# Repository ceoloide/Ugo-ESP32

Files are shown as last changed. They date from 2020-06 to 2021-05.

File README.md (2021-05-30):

# Ugo-ESP32

A 4-button Wi-Fi connected remote, based on the original [Hugo-ESP8266 concept by mcer12](https://github.com/mcer12/Hugo-ESP8266).

## Features

-   4 physical buttons that can trigger up to 7 different actions, one for each button and three for 2-button combinations (B1+B2, B2+B3, B3+B4).
-   Support for Home Assistant auto-discovery, optionally sending device state (button, battery percentage, voltage) after every button push.
-   Support for HTTPS and MQTTS endpoints, although certificate validation is planned but not yet supported.
-   Web UI to configure WiFi and button actions.

## TinyPICO

The code currently depends on a [TinyPICO (original)](https://tinypico.com), since I'm using this board for development. TinyPICO has been selected for its very good low-power draw on deep sleep. Check out Unexpected Maker's [Discord server](https://discord.gg/83Nr7rz) for updates and questions on TinyPICO or this project.

### Ugo-ESP32 TinyPICO Shield

The hardware folder contains the PCB and schematics for a TinyPICO shield version of the Ugo-ESP32, featuring similar overall dimensions (35mm width, 145mm height) and button layout as the [Philips Hue Dimmer Switch](https://www2.meethue.com/en-us/p/hue-dimmer-switch/046677473372), as well as an RGB led for status notifications. It also contains the enclosure design and STL files, which are meant for 3D printing.

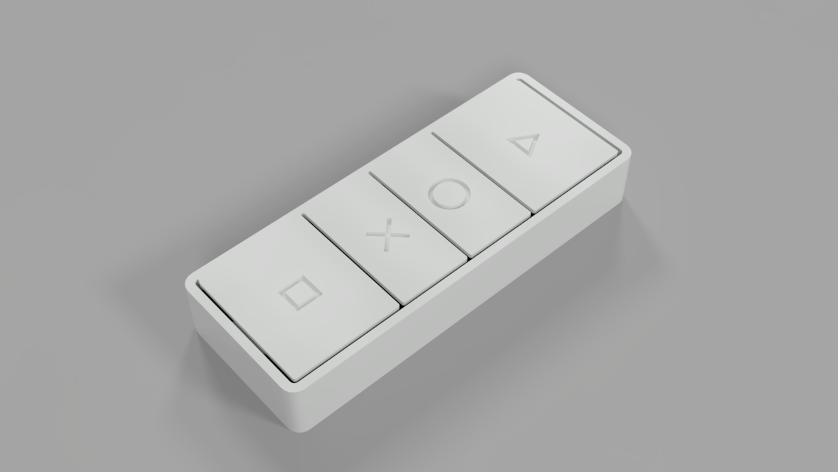
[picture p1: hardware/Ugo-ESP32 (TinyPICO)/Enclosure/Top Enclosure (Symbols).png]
Enclosure top


The board houses the TinyPICO on the back, and can comfortably fit a 60x30x5mm (503060 / 053060) LiPo battery, usually available with a 1300mAh capacity. Early and untested estimates indicate a battery life of roughly 1 year with up to 2 button presses per day.

PCB front

PCB back

## Credits

A huge thanks to:
- [@mcer12](https://github.com/mcer12) for the original [Hugo-ESP8266 concept](https://github.com/mcer12/Hugo-ESP8266)

Shoutout to everyone working on the libraries used for this project:
- [ArduinoJson](https://github.com/bblanchon/ArduinoJson)
- [AsyncTCP](https://github.com/me-no-dev/AsyncTCP)
- [ESPAsyncWebServer](https://github.com/me-no-dev/ESPAsyncWebServer)
- [PubSubClient](https://github.com/knolleary/pubsubclient)
- [TinyPICO-Helper](https://github.com/)

## License 

This software is licensed under the APACHE 2.0 License. See the [license file](LICENSE) for details.

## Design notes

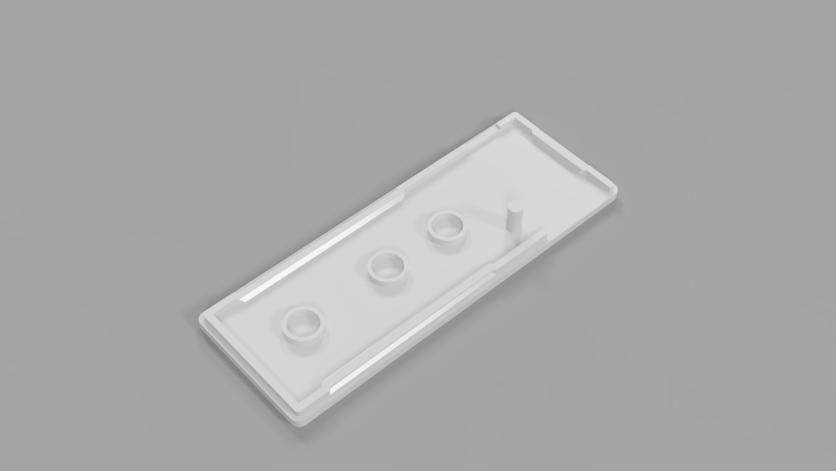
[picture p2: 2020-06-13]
hardware/Ugo-ESP32 (TinyPICO)/Enclosure/Bottom Lid.png

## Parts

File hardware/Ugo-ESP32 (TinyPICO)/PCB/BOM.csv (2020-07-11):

ID | Name | Designator | Footprint | Quantity | Manufacturer Part | Manufacturer | Supplier | Supplier Part | LCSC Assembly
1 | 10uF | C1,C2,C3,C4 | C0603 | 4 | CL10A106KP8NNNC | SAMSUNG | LCSC | C19702 | Yes
2 | 100K | R1,R2,R3,R4 | R0603 | 4 | 0603WAF1003T5E | UniOhm | LCSC | C25803 | Yes
3 | TS-1187A-C-C-B | SW1,SW2,SW3,SW4 | SW-SMD_4P-L5.1-W5.1-P3.70-LS6.4 | 4 | TS-1187A-C-C-B | XKB Enterprise | LCSC | C318889 | Yes
4 | MHT194CRGBCT | D5 | LED-ARRAY-SMD_0603-4P-L1.6-W1.6-BL-RD | 1 | MHT194CRGBCT | MEIHUA | LCSC | C404275 | Yes
5 | M02-JST-2MM-SMT | JP1 | JST-2-SMD | 1
6 | 270 | R5 | R0603 | 1 | 0603WAF2700T5E | UniOhm | LCSC | C22966 | Yes
7 | 820 | R6 | R0603 | 1 | 0603WAF8200T5E | UniOhm | LCSC | C23253 | Yes
8 | 10 | R8 | R0402 | 1 | 0402WGF100JTCE | UniOhm | LCSC | C25077 | Yes
9 | 47 | R7 | R0603 | 1 | 0603WAF470JT5E | UniOhm | LCSC | C23182 | Yes
10 | TinyPICO | NO | TINYPICO | 1 | TinyPICO | Unexpected Maker | Unexpected Maker | TinyPICO

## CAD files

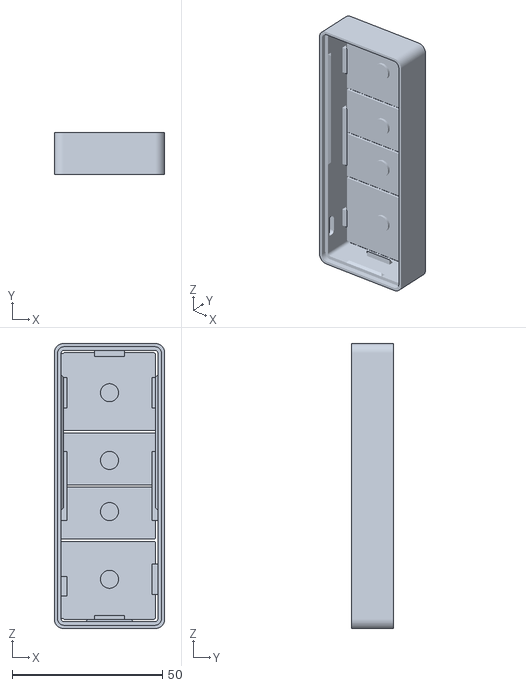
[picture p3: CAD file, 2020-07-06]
hardware/Ugo-ESP32 (TinyPICO)/Enclosure/Top Enclosure (Symbols).stl
36.7 x 14.0 x 94.7

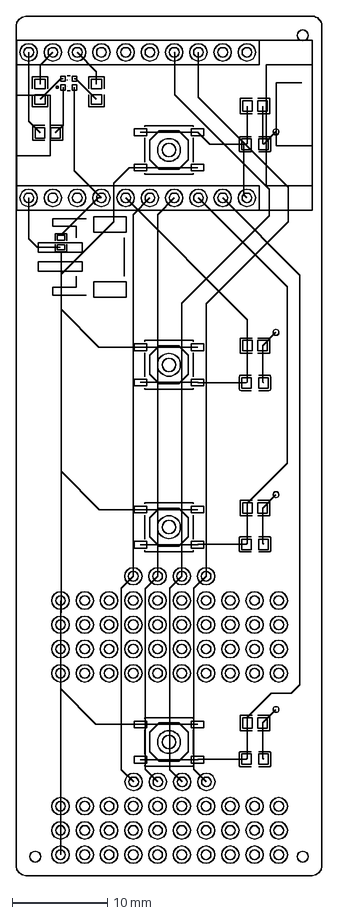
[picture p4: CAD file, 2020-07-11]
hardware/Ugo-ESP32 (TinyPICO)/PCB/EasyEDA/EasyEDA_PCB.dxf
32.0 x 90.0 mm

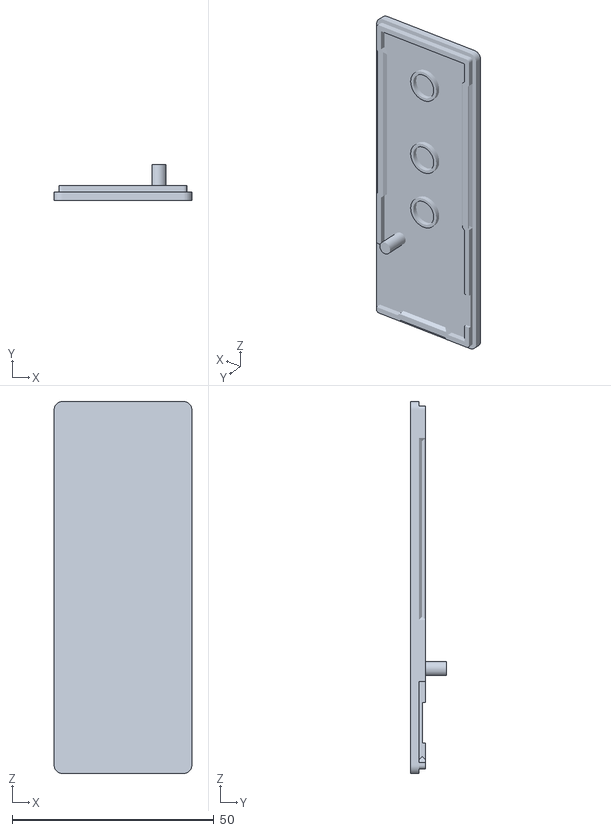
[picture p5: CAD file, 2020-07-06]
hardware/Ugo-ESP32 (TinyPICO)/Enclosure/Bottom Lid.stl
34.1 x 8.80 x 92.1

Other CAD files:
hardware/Ugo-ESP32 (TinyPICO)/Enclosure/Top Enclosure (Plain).stl
hardware/Ugo-ESP32 (TinyPICO)/Enclosure/Ugo-ESP32 (TinyPICO).f3d

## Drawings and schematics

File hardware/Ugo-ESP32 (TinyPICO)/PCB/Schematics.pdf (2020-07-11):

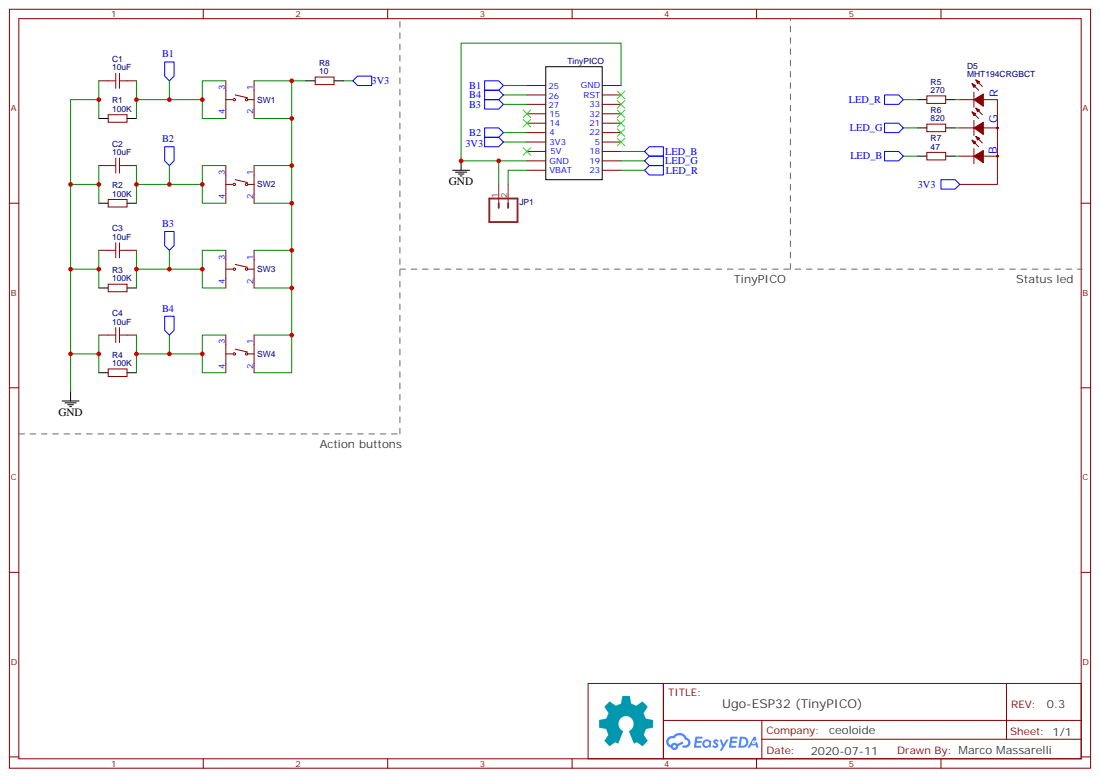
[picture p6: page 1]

Drawn By: Marco Massarelli

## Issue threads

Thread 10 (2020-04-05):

When serving reset.html the CSS is not delivered before device reset

ceoloide, 2020-04-05:
The CSS of the reset.html page is not delivered in time for display before the device goes into sleep and resets. This is related to Issue #4.

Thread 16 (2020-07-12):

Fix minor imperfections in the enclosure

ceoloide, 2020-07-12:
- Length should be increased from 90.2mm to ~90.45mm
- Material should be added again on the back of the buttons to avoid symbols looking bad
- Revert the change in slit size between buttons since it looks worse in practice

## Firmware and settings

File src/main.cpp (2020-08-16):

/*
Copyright 2020 Marco Massarelli

Licensed under the Apache License, Version 2.0 (the "License");
you may not use this file except in compliance with the License.
You may obtain a copy of the License at

    http://www.apache.org/licenses/LICENSE-2.0

Unless required by applicable law or agreed to in writing, software
distributed under the License is distributed on an "AS IS" BASIS,
WITHOUT WARRANTIES OR CONDITIONS OF ANY KIND, either express or implied.
See the License for the specific language governing permissions and
limitations under the License.
*/

#include <Arduino.h>
#include <TinyPICO.h>
#include "main.h"

// Initialise the TinyPICO library
TinyPICO tp = TinyPICO();

uint8_t deviceMode = NORMAL_MODE;

uint8_t button;

bool otaModeStarted = false;
volatile bool ledState = false;

// TIMERS
unsigned long otaMillis, ledMillis, configTimer, otaTimer;

byte mac[6];
AsyncWebServer server(80);

byte dnsPort = 53;
DNSServer dnsServer;

WiFiClient espClientInsecure;
PubSubClient mqttClientInsecure(espClientInsecure);
WiFiClientSecure espClientSecure;
PubSubClient mqttClientSecure(espClientSecure);

DynamicJsonDocument json(2048); // config buffer

/* You only need to format SPIFFS the first time you run a
   test or else use the SPIFFS plugin to create a partition
   https://github.com/me-no-dev/arduino-esp32fs-plugin */
#define FORMAT_SPIFFS_IF_FAILED false // false

//#define BUTTON_PIN_BITMASK 0x300000000 // 2^33 in hex
//                                  10 // Pin  4
//                                4000 // Pin 14
//                                8000 // Pin 15
//                             2000000 // Pin 25
//                             4000000 // Pin 26
//                             8000000 // Pin 27
//                           100000000 // Pin 32
//                           200000000 // Pin 33
//#define BUTTON_PIN_BITMASK 0x00800C010 // 4 + 14 + 15 + 27
//#define BUTTON_PIN_BITMASK 0x308000010 // 4 + 33 + 32 + 27
#define BUTTON_PIN_BITMASK 0x00E000010 // 4 + 25 + 26 + 27

#include "actions.h"
#include "config_portal.h"
#include "ota.h"
#include "hass_register.h"

void setup()
{
    Serial.begin(115200);
    Serial.println("");

#if CORE_DEBUG_LEVEL == 5
    printWakeupReason();
    printResetReason();
    batteryPercentage();
#endif

#if ENABLE_PCB_LED
    ledcSetup(RED_LED_PWM_CHANNEL, PWM_FREQUENCY, PWM_RESOLUTION);
    ledcAttachPin(RED_LED_PIN, RED_LED_PWM_CHANNEL);
    GPIO.func_out_sel_cfg[RED_LED_PIN].inv_sel = INVERT_LED_PWM_SENSE;
#ifdef ENABLE_V_0_2_PCB_LED_FIX
    pinMode(COMMON_ANODE_PIN, OUTPUT);
    digitalWrite(COMMON_ANODE_PIN, LOW);  // Power off
#else
    ledcSetup(GREEN_LED_PWM_CHANNEL, PWM_FREQUENCY, PWM_RESOLUTION);
    ledcAttachPin(GREEN_LED_PIN, GREEN_LED_PWM_CHANNEL);
    GPIO.func_out_sel_cfg[GREEN_LED_PIN].inv_sel = INVERT_LED_PWM_SENSE;
#endif
    ledcSetup(BLUE_LED_PWM_CHANNEL, PWM_FREQUENCY, PWM_RESOLUTION);
    ledcAttachPin(BLUE_LED_PIN, BLUE_LED_PWM_CHANNEL);
    GPIO.func_out_sel_cfg[BLUE_LED_PIN].inv_sel = INVERT_LED_PWM_SENSE;
#endif

    // Go to sleep immediately if woke up for something not related to deep sleep
    if (esp_reset_reason() != ESP_RST_DEEPSLEEP)
    {
        Serial.println("Skipping button detection.");
        blinkResetReason();
        goToSleep();
    }

    // Prepare the pins
    pinMode(button1_pin, INPUT);
    pinMode(button2_pin, INPUT);
    pinMode(button3_pin, INPUT);
    pinMode(button4_pin, INPUT);

    // This small delay is required for correct button detection
    delay(10);

    button = readButtons();

    if (!SPIFFS.begin(FORMAT_SPIFFS_IF_FAILED))
    {
        if (!SPIFFS.begin())
        {
            Serial.println("SPIFFS Mount Failed :: Needs formatting?");
            return;
        }
        if (FORMAT_SPIFFS_IF_FAILED)
        {
            Serial.println("SPIFFS Mount Failed :: FORMATTING");
        }
    }

    WiFi.macAddress(mac);
    readConfig();

    const char *ssid = json["id"].as<const char *>();
    const char *pass = json["pw"].as<const char *>();
    const char *ip = json["ip"].as<const char *>();
    const char *gw = json["gw"].as<const char *>();
    const char *sn = json["sn"].as<const char *>();
    const char *d1 = json["d1"].as<const char *>();
    const char *d2 = json["d2"].as<const char *>();

    if (json["id"] != "" && json["pw"] != "")
    {
        WiFi.mode(WIFI_STA);

        IPAddress ip_address, gateway_ip, subnet_mask, dns_address_1, dns_address_2;
        if (ip[0] != '\0' && ip_address.fromString(String(ip)) &&
            gw[0] != '\0' && gateway_ip.fromString(String(gw)) &&
            sn[0] != '\0' && subnet_mask.fromString(String(sn)))
        {

            if (d1[0] != '\0' && dns_address_1.fromString(String(d1)))
            {
                if (d2[0] != '\0' && dns_address_2.fromString(String(d2)))
                {
                    if (WiFi.config(ip_address, gateway_ip, subnet_mask, dns_address_1, dns_address_2))
                    {
                        Serial.println("STA successfully configured with IP, Gateway, Subnet, Primary DNS, Secondary DNS.");
                    }
                    else
                    {
                        Serial.println("STA failed to configure with IP, Gateway, Subnet, Primary DNS, Secondary DNS. Using auto config instead.");
                        Serial.println("[ip]: " + String(ip));
                        Serial.println("[gw]: " + String(gw));
                        Serial.println("[sn]: " + String(sn));
                        Serial.println("[d1]: " + String(d1));
                        Serial.println("[d2]: " + String(d2));
                    }
                }
                else
                {
                    if (WiFi.config(ip_address, gateway_ip, subnet_mask, dns_address_1))
                    {
                        Serial.println("STA successfully configured with IP, Gateway, Subnet, Primary DNS.");
                    }
                    else
                    {
                        Serial.println("STA failed to configure with IP, Gateway, Subnet, Primary DNS. Using auto config instead.");
                        Serial.println("[ip]: " + String(ip));
                        Serial.println("[gw]: " + String(gw));
                        Serial.println("[sn]: " + String(sn));
                        Serial.println("[d1]: " + String(d1));
                    }
                }
            }
            else
            {
                if (WiFi.config(ip_address, gateway_ip, subnet_mask))
                {
                    Serial.println("STA successfully configured with IP, Gateway, Subnet.");
                }
                else
                {
                    Serial.println("STA failed to configure with IP, Gateway, Subnet. Using auto config instead.");
                    Serial.println("[ip]: " + String(ip));
                    Serial.println("[gw]: " + String(gw));
                    Serial.println("[sn]: " + String(sn));
                }
            }
        }
        else
        {
            Serial.println("Failed to configure static IP.");
            Serial.println("[ip]: " + String(ip));
            Serial.println("[gw]: " + String(gw));
            Serial.println("[sn]: " + String(sn));
        }

        WiFi.begin(ssid, pass);

        for (int i = 0; i < 50; i++)
        {
            if (WiFi.status() != WL_CONNECTED)
            {
                if (i > 40)
                {
                    deviceMode = CONFIG_MODE;
                    Serial.print("Failed to connect to: ");
                    Serial.println(ssid);
                    break;
                }
                delay(100);
            }
            else
            {
                Serial.println("Wifi connected...");
                Serial.print("SSID: ");
                Serial.println(WiFi.SSID());
                Serial.print("Mac address: ");
                Serial.println(WiFi.macAddress());
                Serial.print("IP: ");
                Serial.println(WiFi.localIP());
                break;
            }
        }
    }
    else
    {
        deviceMode = CONFIG_MODE;
        Serial.println("No credentials set, going to config mode");
    }

    String ota_name = OTA_NAME + macLastThreeSegments(mac);
    ArduinoOTA.setHostname(ota_name.c_str());

    ArduinoOTA.onStart([]() {
        Serial.println("OTA UPLOAD STARTED...");
        setLedColor(0, 0, 255);
    });
}

void loop()
{
    // Detect button combo to enter config mode
    toggleConfigMode();

    if (deviceMode == CONFIG_MODE)
    {
        Serial.println("STARTING CONFIG ACCESS POINT...");
        setLedColor(255, 255, 0);
        startConfigPortal();
        Serial.println("RETURNING TO NORMAL MODE...");
        deviceMode = NORMAL_MODE;
        return;
    }

    // Detect button combo to enter Hass.io register mode
    toggleHassRegisterMode();

    if (deviceMode == HASS_REGISTER_MODE)
    {
        Serial.println("REGISTERING WITH HASS.IO...");
        setLedColor(255, 0, 255);
        startHassRegister();
        Serial.println("RETURNING TO NORMAL MODE...");
        deviceMode = NORMAL_MODE;
        return;
    }

    // Detect button combo to enter OTA mode
    toggleOTAMode();

    if (deviceMode == OTA_MODE)
    {
        Serial.println("WAITING FOR OTA UPDATE...");
        setLedColor(0, 255, 255);
        startOTA();
        Serial.println("RETURNING TO NORMAL MODE...");
        deviceMode = NORMAL_MODE;
        return;
    }

    if (deviceMode != NORMAL_MODE)
        return;

    handleButtonAction();

    switch (button)
    {
    case 1:
        setLedColor(255, 0, 0);
        break;
    case 2:
        setLedColor(0, 255, 0);
        break;
    case 3:
        setLedColor(0, 0, 255);
        break;
    case 4:
        setLedColor(0, 255, 255);
        break;
    case 5:
        setLedColor(255, 0, 255);
        break;
    case 6:
        setLedColor(255, 255, 0);
        break;
    case 7:
        setLedColor(255, 255, 255);
        break;
    default:
        break;
    }

    if (json["ha_enabled"].as<bool>())
    {
        publishDeviceState();
    }

    goToSleep();
}

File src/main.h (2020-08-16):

/*
Copyright 2020 Marco Massarelli

Licensed under the Apache License, Version 2.0 (the "License");
you may not use this file except in compliance with the License.
You may obtain a copy of the License at

    http://www.apache.org/licenses/LICENSE-2.0

Unless required by applicable law or agreed to in writing, software
distributed under the License is distributed on an "AS IS" BASIS,
WITHOUT WARRANTIES OR CONDITIONS OF ANY KIND, either express or implied.
See the License for the specific language governing permissions and
limitations under the License.
*/

#pragma once

#include <Arduino.h>
#include <TinyPICO.h>

// APA102 Dotstar
#define DOTSTAR_PWR 13
#define DOTSTAR_DATA 2
#define DOTSTAR_CLK 12

// Battery
#define BAT_CHARGE 34
#define BAT_VOLTAGE 35

#ifdef ESP32
#include <WiFiClientSecure.h>
#include <AsyncTCP.h>
#include <DNSServer.h>
#else
#error Platform not supported
#endif
#include <ESPAsyncWebServer.h>
#include <ESPmDNS.h>

#include <FS.h>
#include <SPIFFS.h>
#include <ArduinoJson.h>

#include <ArduinoOTA.h>
#include <HTTPClient.h>
#include <PubSubClient.h>

#define OTA_NAME "Ugo_" // Last 6 MAC address characters will be appended at the end of the OTA name, "Ugo_XXXXXX" by default
#define AP_NAME "Ugo_"  // Last 6 MAC address characters will be appended at the end of the AP name, "Ugo_XXXXXX" by default

// Button PINs
#define button1_pin 25
#define button2_pin 4
#define button3_pin 27
#define button4_pin 26

// On the Ugo-ESP32 (TinyPICO) v0.2 PCB, the RGB led has been rotated 180 degrees
// This means the Green LED pin is now the common anode, the 3V3 pin is the Green LED, which is now always off
// And the Red and Blue pins are reversed. It's also not possible to turn on both Red and Blue leds at the same time.
#ifdef ENABLE_V_0_2_PCB_LED_FIX
#define RED_LED_PIN 18
#define COMMON_ANODE_PIN 19
#define BLUE_LED_PIN 23
#else
#define RED_LED_PIN 23
#define GREEN_LED_PIN 19
#define BLUE_LED_PIN 18
#endif

#define RED_LED_PWM_CHANNEL 0
#define GREEN_LED_PWM_CHANNEL 1
#define BLUE_LED_PWM_CHANNEL 2

#define PWM_FREQUENCY 5000
#define PWM_RESOLUTION 8

#if !defined(RGB_COMMON_ANODE) && !defined(RGB_COMMON_CATHODE)
// Defaulting to RGB_COMMON_ANODE since that's the RGB LED on the Ugo-ESP32 (TinyPICO) PCB v0.2
#define RGB_COMMON_ANODE
#endif

#ifdef RGB_COMMON_CATHODE
#define RGB_LED_ON HIGH
#define RGB_LED_OFF LOW
#define INVERT_LED_PWM_SENSE 0
#endif

#if (defined(RGB_COMMON_ANODE) && defined(RGB_COMMON_CATHODE)) || defined(RGB_COMMON_ANODE)
#define RGB_LED_ON LOW
#define RGB_LED_OFF HIGH
#define INVERT_LED_PWM_SENSE 1
#endif

#define LED_CHANGE_DELAY 50  // Amount of time (ms) to wait after LED color / status change 

#define OTA_TIMEOUT 300000    // 5 minutes
#define CONFIG_TIMEOUT 300000 // 5 minutes

// DO NOT CHANGE DEFINES BELOW
#define NORMAL_MODE 0
#define OTA_MODE 1
#define CONFIG_MODE 2
#define HASS_REGISTER_MODE 3

// If the max message size is too small, throw an error at compile time. See PubSubClient.cpp line 359
#if MQTT_MAX_PACKET_SIZE < 512
#error "MQTT_MAX_PACKET_SIZE is too small in libraries/PubSubClient/src/PubSubClient.h, increase it to 512"
#endif

#define MQTT_PUBLISH_TRIES 3

// Initialise the TinyPICO library
extern TinyPICO tp;

extern uint8_t deviceMode;

extern uint8_t button;

extern bool otaModeStarted;
extern volatile bool ledState;

// TIMERS
extern unsigned long otaMillis, ledMillis, configTimer, otaTimer;

extern byte mac[6];
extern AsyncWebServer server;

extern byte dnsPort;
extern DNSServer dnsServer;

extern WiFiClient espClientInsecure;
extern PubSubClient mqttClientInsecure;
extern WiFiClientSecure espClientSecure;
extern PubSubClient mqttClientSecure;

extern DynamicJsonDocument json; // config buffer

/* You only need to format SPIFFS the first time you run a
   test or else use the SPIFFS plugin to create a partition
   https://github.com/me-no-dev/arduino-esp32fs-plugin */
#define FORMAT_SPIFFS_IF_FAILED false // false

//#define BUTTON_PIN_BITMASK 0x300000000 // 2^33 in hex
//                                  10 // Pin  4
//                                4000 // Pin 14
//                                8000 // Pin 15
//                             2000000 // Pin 25
//                             4000000 // Pin 26
//                             8000000 // Pin 27
//                           100000000 // Pin 32
//                           200000000 // Pin 33
//#define BUTTON_PIN_BITMASK 0x00800C010 // 4 + 14 + 15 + 27
//#define BUTTON_PIN_BITMASK 0x308000010 // 4 + 33 + 32 + 27
#define BUTTON_PIN_BITMASK 0x00E000010 // 4 + 25 + 26 + 27

void setup();

void loop();

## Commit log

2020-04-04 Added mention of TinyPICO dev board.
2020-04-05 Moved source files under a different directory to make it compatible with Arduino IDE, pending the migration to PlatformIO.
2020-04-05 Ugo-ESP32 now serves HTML files from SPIFFS, processing them as templates (Issue #4). Some additional work is needed to maintain 302 return codes and handle redirect web page via SPIFFS.
2020-04-18 Updated battery percentage estimate based on calibrated battery discharge.
2020-04-19 Restructured the MQTT code a bit, added MQTT Device Discovery for Hass.io / Home Assistant, though IP is still manually set.
2020-04-20 Added disconnect after publishing button topic (Issue #2).
2020-04-21 Initial refactoring to switch to PlatformIO (Issue #5).
    [actions.cpp, config_portal.cpp, hass_register.cpp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]
2020-04-21 Switching back to sglahn/platformio-core docker image, this time specifying 3.6.0 platformio version, for compatibility.
2020-04-22 Updated platformio.ini to match Arduino IDE settings and removed FW_VERSION from main.*.
2020-04-24 Fixed some errors in the MQTT URI parsing (Issue #2).
    [actions.cpp]
2020-04-24 Fixed incorrect topic detection from MQTT URI (Issue #2).
    [actions.cpp]
2020-04-25 Added improvements to the Home Assistant integration (Issue #13).
    [actions.cpp, config_portal.cpp, hass_register.cpp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]
2020-04-25 Fixed some errors in the WiFi connection code preventing settings from being properly applied.
    [main.cpp]
2020-04-25 Refactored and further fixed static IP and DNS code, which is now working as intended.
    [main.cpp]
2020-04-26 Added basic support for secure MQTT connections (Issue #2).
    [actions.cpp, hass_register.cpp, main.cpp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]
2020-04-27 Switched from include guards to pragma in header files.
2020-04-27 Updated Home Assistant device configuration to also report voltage and button.
2020-04-29 Made MQTT connect and publish more reliable (Issue #2).
    [actions.cpp, hass_register.cpp, main.cpp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]
2020-04-30 Fixed mqtt connection retry logic.
    [actions.cpp]
2020-05-08 Added the first revision of the TinyPICO daughterboard / shield for Ugo-ESP32.
    [BOM.csv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]
2020-05-10 Added PCB images and a brief description of the TinyPICO shield.
2020-05-20 Added STL files for the enclosure (first revision) and reorganized fodlers.
    [BOM.csv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]
2020-05-24 Second revision of the enclosure design
    1) extended the internal lips to stop the PCB
    2) increased the depth of the receiving slots of the cantilevers, and moved the cantilevers closer to the edge of the lid to increase the snap action
    3) changed the button cutout pattern to be left-hinged and increased the slot width to 0.5mm
    4) added the micro-usb cut-out on the side
    5) added two spacers to better support the top part of the bottom lid
    6) added some initial shapes on the buttons to distinguish the orientation
    [Ugo-ESP32 (TinyPICO v0.1) - Bottom Lid.stl, Ugo-ESP32 (TinyPICO v0.1) - Top Enclosure (Triangle + Square).stl, Ugo-ESP32 (TinyPICO v0.1) - Top Enclosure.stl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]
2020-05-24 Updated the top enclosure rendering
2020-05-25 Updated to match Rev 2 of the PCB
    [BOM.csv, Pick And Place.csv]
2020-06-07 Second revision of the enclosure and PCB design.
    Updated the PCB for its second revision, and modified the enclosure to address many print issues and some design flaws.
    [Bottom Lid.stl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]
2020-06-07 Updated Fusion 360 archive to match the latest revision
    [Ugo-ESP32 (TinyPICO).f3d]
2020-06-13 New snap fit design for the enclosure
    [Bottom Lid.stl, Top Enclosure (Plain).stl, Top Enclosure (Symbols).stl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]
2020-07-06 Fixed enclosure tolerances and outer shell thickness
    - Increased shell thickness by 0.25mm to account for filament size
    - Fixed micro USB cut-out position and size
    - Fixed magnet holder thickness to account for out-of-spec battery thickness
    - Minor tolerance fixes
    [Bottom Lid.stl, Top Enclosure (Plain).stl, Top Enclosure (Symbols).stl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]
2020-07-11 Updated the PCB design, removing diodes and reducing the resistance.
    [BOM.csv, EasyEDA_PCB.dxf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]
2020-07-11 Updated PIN assignment for buttons to match PCV v0.2 layout. Increased CPU speed to 240MHz.
2020-08-15 Added initial / basic support for PCB RGB LED.
2020-08-15 Fixed stupid typos that were causing the build to fail.
    [actions.cpp, main.cpp, main.h]
2020-08-15 Added support for PCB v0.2 with rotated LED, and fixed On / Off variables.
    [actions.cpp, main.cpp, main.h]
2020-08-15 Added support for PWM / dimming of PCB RGB led.
2020-08-15 Fixed typo in setLedColor() function.
    [actions.cpp]
2020-08-16 Fixed PCB LED flash PCB LED had dull glow after button push (and before main PCB light-up) Tweak LED PWM GPIO to invert sense of output Changed setLedColour() to no longer use sense invert.
    [actions.cpp, main.cpp]
2020-08-16 Small changes to adapt the merged code to the PCB v2.0 fix.
    [actions.cpp, main.cpp, main.h]
